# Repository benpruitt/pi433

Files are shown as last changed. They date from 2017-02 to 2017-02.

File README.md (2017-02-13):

# pi433

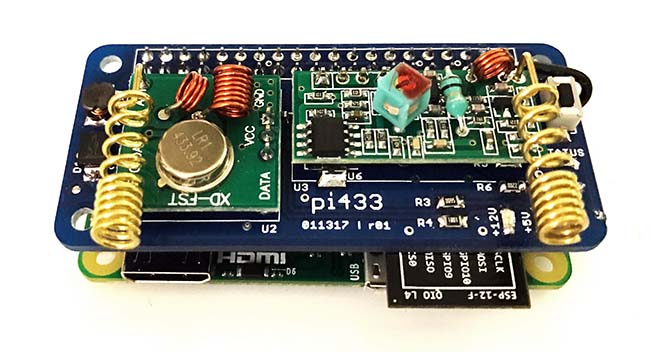
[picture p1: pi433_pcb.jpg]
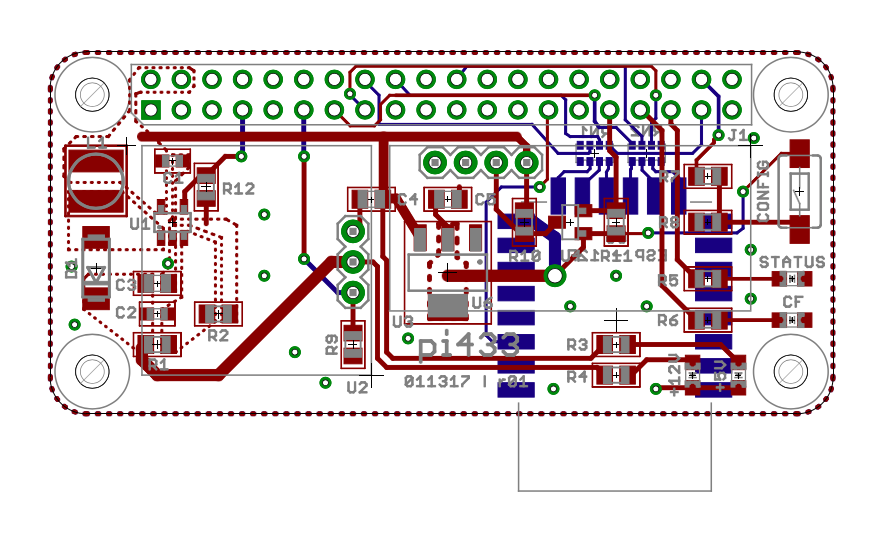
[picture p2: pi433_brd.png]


Raspberry Pi Zero-based Etekcity 433 MHz wireless outlet control. Repo contains
control code and PCB designs.

## Features

* On/off control of Etekcity 433 MHz outlets
* Configurable via a single JSON file
* Ability to group switches into functional groups (e.g., "living room lights")
* Integration with Amazon Echo voice control
* RESTful API exposes outlet control
* Lightweight mobile frontend for manual control

## Dependencies

* [C] wiringPi
* [Python] Cython [optional]
* [Python] gevent
* [Python] rpi.GPIO

## Installation

The latest Rasbian image should include several of the dependencies, including
`RPi-GPIO` and `wiringPi`. The wifi on the Pi zero daughterboard is provided
by an ESP-12F that the Broadcom chip talks to over an SDIO interface. Here
are instructions for updating the device tree & building the module to
support the ESP-12F: https://oshlab.com/esp8266-raspberry-pi-gpio-wifi/

After following the above instructions just set up wifi as usual by editing
`/etc/network/interfaces` and `/etc/wpa_supplicant/wpa_supplicant.conf`.

Next install the remaining python dependencies. I would recommend using
`apt-get` rather than `pip` (to avoid compile times) if you don't mind
installing in your system site packages directory.

Finally:

`sudo python install.py`
_(admin privileges necessary to install systemd service)_

## Installation notes

`pi433` is tested on Raspian under the system Python (2.7.7) / in a
virtual env. `pi433` is not installed into the Python site packages
directory, but rather is copied into `~/.pi433`. The install script copies
the main module directory along with the cli into `~/.pi433` and creates /
configures the `systemd` service necessary to run `pi433` at startup.

The repo contains a pre-built version of the Cython wrapper for the rc-switch
library, so unless you make modifications you shouldn't need Cython. (although
if you do need it, make sure you install via `sudo apt-get install cython`
to avoid the lonnnngg build time you'll experience through `pip`).

## Configuration

The included `config.json` file is also copies into `~/.pi433` and contains
the specifications for the RF outlets / groups that you want to control.

## Todo

* Include RF sniffing interface
* Implement config button functionality
* Better antenna for TX

## Licensing

All code is released under the MIT license with the exception of:

* Unmodified source code from rc-switch is LGPL v2.1:

        pi433/RCSwitch.cpp
        pi433/RCSwitch.h

## Acknowledgements

Inspired by (and derived from [see code comments]):
* rc-switch - https://github.com/sui77/rc-switch
* fauxmo - https://github.com/makermusings/fauxmo / https://github.com/n8henrie/fauxmo

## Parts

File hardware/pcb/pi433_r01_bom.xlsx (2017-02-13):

UID | REF | PART TYPE | #/BOARD | DES | MFG DES | MFG P/N | MFG | SUPPLIER | SUPPLIER P/N | UNIT SIZE | $/UNIT | $/BOARD | DIGIKEY ORDER 1/7/16
PI433_01_01 | R1 | Resistor | 1 | 0805 432k | RES SMD 432K OHM 1% 1/8W 0805 | RC0805FR-07432KL (http://www.digikey.com/product-detail/en/yageo/RC0805FR-07432KL/311-432KCRCT-ND/730906) | Yageo | Digikey | 311-432KCRCT-ND (http://www.digikey.com/product-detail/en/yageo/RC0805FR-07432KL/311-432KCRCT-ND/730906) | 1 | 0.1 | 0.1 | 4
PI433_01_02 | R2 | Resistor | 1 | 0805 49.9k | RES SMD 49.9K OHM 1% 1/8W 0805 | RC0805FR-0749K9L (http://www.digikey.com/product-detail/en/yageo/RC0805FR-0749K9L/311-49.9KCRCT-ND/730932) | Yageo | Digikey | 311-49.9KCRCT-ND (http://www.digikey.com/product-detail/en/yageo/RC0805FR-0749K9L/311-49.9KCRCT-ND/730932) | 1 | 0.1 | 0.1 | 4
PI433_01_03 | R3 | Resistor | 1 | 0805 560 | RES SMD 560 OHM 1% 1/8W 0805 | RC0805FR-07560RL (http://www.digikey.com/product-detail/en/yageo/RC0805FR-07560RL/311-560CRCT-ND/730983) | Yageo | Digikey | 311-560CRCT-ND (http://www.digikey.com/product-detail/en/yageo/RC0805FR-07560RL/311-560CRCT-ND/730983) | 1 | 0.1 | 0.1 | 4
PI433_01_04 | R4 | Resistor | 1 | 0805 1.8k | RES SMD 1.8K OHM 1% 1/8W 0805 | RC0805FR-071K8L (http://www.digikey.com/product-detail/en/yageo/RC0805FR-071K8L/311-1.80KCRCT-ND/730467) | Yageo | Digikey | 311-1.80KCRCT-ND (http://www.digikey.com/product-detail/en/yageo/RC0805FR-071K8L/311-1.80KCRCT-ND/730467) | 1 | 0.1 | 0.1 | 4
PI433_01_05 | R5, R6 | Resistor | 2 | 0805 220 | RES SMD 220 OHM 1% 1/8W 0805 | RC0805FR-07220RL (http://www.digikey.com/product-detail/en/yageo/RC0805FR-07220RL/311-220CRCT-ND/730688) | Yageo | Digikey | 311-220CRCT-ND (http://www.digikey.com/product-detail/en/yageo/RC0805FR-07220RL/311-220CRCT-ND/730688) | 1 | 0.1 | 0.2 | 8
PI433_01_06 | R7 | Resistor | 1 | 0805 1k | RES SMD 1K OHM 1% 1/8W 0805 | RC0805FR-071KL (http://www.digikey.com/product-detail/en/yageo/RC0805FR-071KL/311-1.00KCRCT-ND/730391) | Yageo | Digikey | 311-1.00KCRCT-ND (http://www.digikey.com/product-detail/en/yageo/RC0805FR-071KL/311-1.00KCRCT-ND/730391) | 1 | 0.1 | 0.1 | 4
PI433_01_07 | R8, R9, R10, R11, R12 | Resistor | 5 | 0805 10k | RES SMD 10K OHM 1% 1/8W 0805 | RC0805FR-0710KL (http://www.digikey.com/product-detail/en/yageo/RC0805FR-0710KL/311-10.0KCRCT-ND/730482) | Yageo | Digikey | 311-10.0KCRCT-ND (http://www.digikey.com/product-detail/en/yageo/RC0805FR-0710KL/311-10.0KCRCT-ND/730482) | 1 | 0.1 | 0.5 | 20
PI433_01_08 | C1 | Capacitor | 1 | 0603 0.1 uF | CAP CER 1UF 10V X5R 0603 | GRM188R61A105K | Murata | Digikey | 490-6408-1-ND (http://www.digikey.com/product-detail/en/murata-electronics-north-america/GRM188R61A105KA61J/490-6408-1-ND/3845605) | 1 | 0.1 | 0.1 | 4
PI433_01_09 | C2 | Capacitor | 1 | 0603 15 pF | CAP CER 15PF 50V NP0 0603 | GCM1885C1H150JA16D (http://www.digikey.com/product-detail/en/murata-electronics-north-america/GCM1885C1H150JA16D/490-4957-1-ND/1765276) | Murata | Digikey | 490-4957-1-ND (http://www.digikey.com/product-detail/en/murata-electronics-north-america/GCM1885C1H150JA16D/490-4957-1-ND/1765276) | 1 | 0.1 | 0.1 | 4
PI433_01_10 | C3 | Capacitor | 1 | 0603 4.7 uF | CAP CER 4.7UF 16V X5R 0805 | GRM21BR61C475K | Murata | Digikey | 490-7214-1-ND (http://www.digikey.com/product-detail/en/murata-electronics-north-america/GRM21BR61C475KA88K/490-7214-1-ND/3991200) | 1 | 0.17 | 0.17 | 4
PI433_01_11 | L1 | Inductor | 1 | 4.7 uH 1.7 A | FIXED IND 4.7UH 1.7A 94 MOHM SMD | SDR0403-4R7ML | Bourns | Digikey | SDR0403-4R7MLCT-ND (http://www.digikey.com/product-detail/en/bourns-inc/SDR0403-4R7ML/SDR0403-4R7MLCT-ND/2127096) | 1 | 0.47 | 0.47 | 4
PI433_01_12 | U1 | Regulator | 1 | 1.4A boost | IC REG BOOST ADJ 1.4A TSOT23-5 | SC4503TSKTRT (http://www.digikey.com/product-detail/en/semtech-corporation/SC4503TSKTRT/SC4503TSKCT-ND/1249536) | Semtech | Digikey | SC4503TSKCT-ND (http://www.digikey.com/product-detail/en/semtech-corporation/SC4503TSKTRT/SC4503TSKCT-ND/1249536) | 1 | 1.92 | 1.92 | 4
PI433_01_13 | U2, U3 | 433 MHz Transmitter / Receiver | 1 | 433 MHz Transmitter / Receiver | N/A | N/A | SMAKN | Amazon | B00M2CUALS (https://www.amazon.com/SMAKN-433Mhz-Transmitter-Receiver-Arduino/dp/B00M2CUALS) | 1 | 6.66 | 6.66
PI433_01_14 | U4 | MOSFET | 1 | Level coversion MOSFET | MOSFET N-CH 50V 220MA SOT-23 | BSS138 (http://www.digikey.com/product-detail/en/fairchild-on-semiconductor/BSS138/BSS138CT-ND/244294) | Fairchild | Digikey | BSS138CT-ND (http://www.digikey.com/product-detail/en/fairchild-on-semiconductor/BSS138/BSS138CT-ND/244294) | 1 | 0.22 | 0.22 | 4
PI433_01_15 | U5 | WIFI Transceiver | 1 | SDIO interface WiFi transceiver | N/A | ESP-12F | Yison | GearBest | ESP-12F (http://www.gearbest.com/transmitters-receivers-module/pp_315638.html) | 1 | 3.19 | 3.19 | 4
PI433_01_16 | S1 | Switch | 1 | Tactile switch | SWITCH TACTILE SPST-NO 0.05A 12V | RS-032G05A3-SM RT (http://www.digikey.com/product-detail/en/c-k/RS-032G05A3-SM-RT/CKN10388CT-ND/2747197) | C&K | Digikey | CKN10388CT-ND (http://www.digikey.com/product-detail/en/c-k/RS-032G05A3-SM-RT/CKN10388CT-ND/2747197) | 1 | 0.56 | 0.56 | 4
PI433_01_17 | LED1, LED2, LED3, LED4 | LED | 4 | LED | LED GREEN CLEAR 0805 SMD | LTST-C171GKT (http://www.digikey.com/product-detail/en/lite-on-inc/LTST-C171GKT/160-1423-1-ND/386792) | Lite-On | Digikey | 160-1423-1-ND (http://www.digikey.com/product-detail/en/lite-on-inc/LTST-C171GKT/160-1423-1-ND/386792) | 1 | 0.29 | 1.16 | 16

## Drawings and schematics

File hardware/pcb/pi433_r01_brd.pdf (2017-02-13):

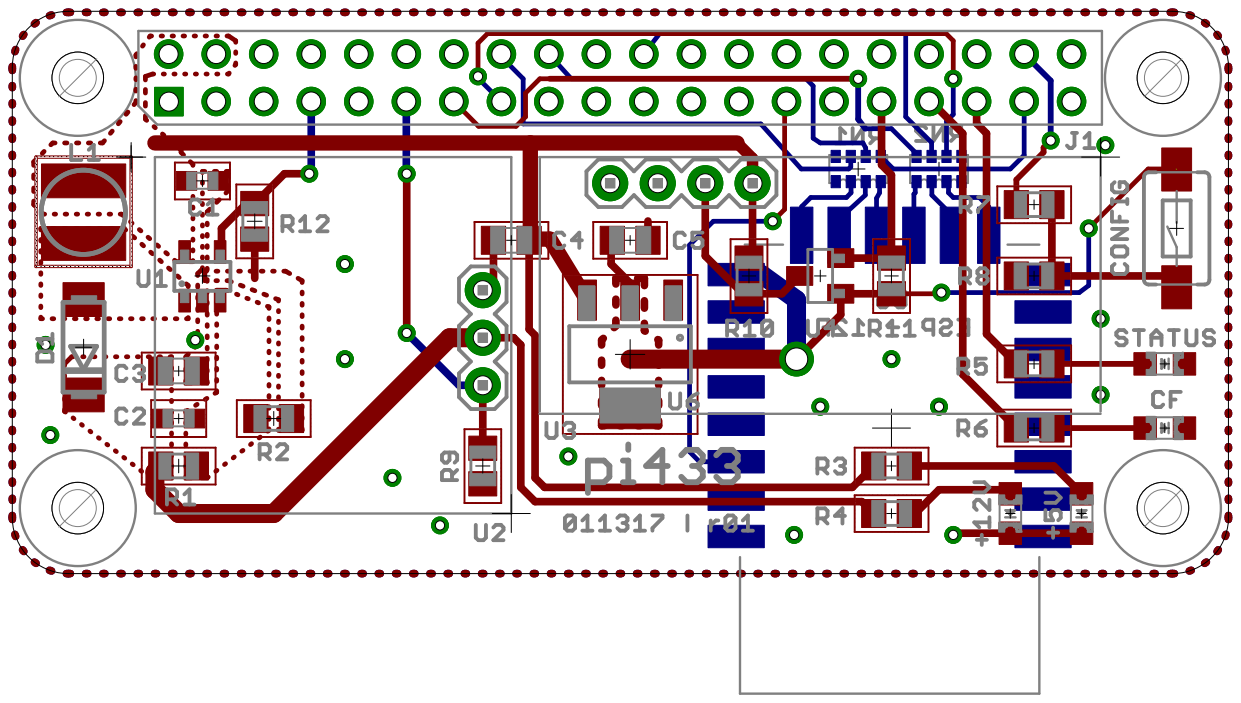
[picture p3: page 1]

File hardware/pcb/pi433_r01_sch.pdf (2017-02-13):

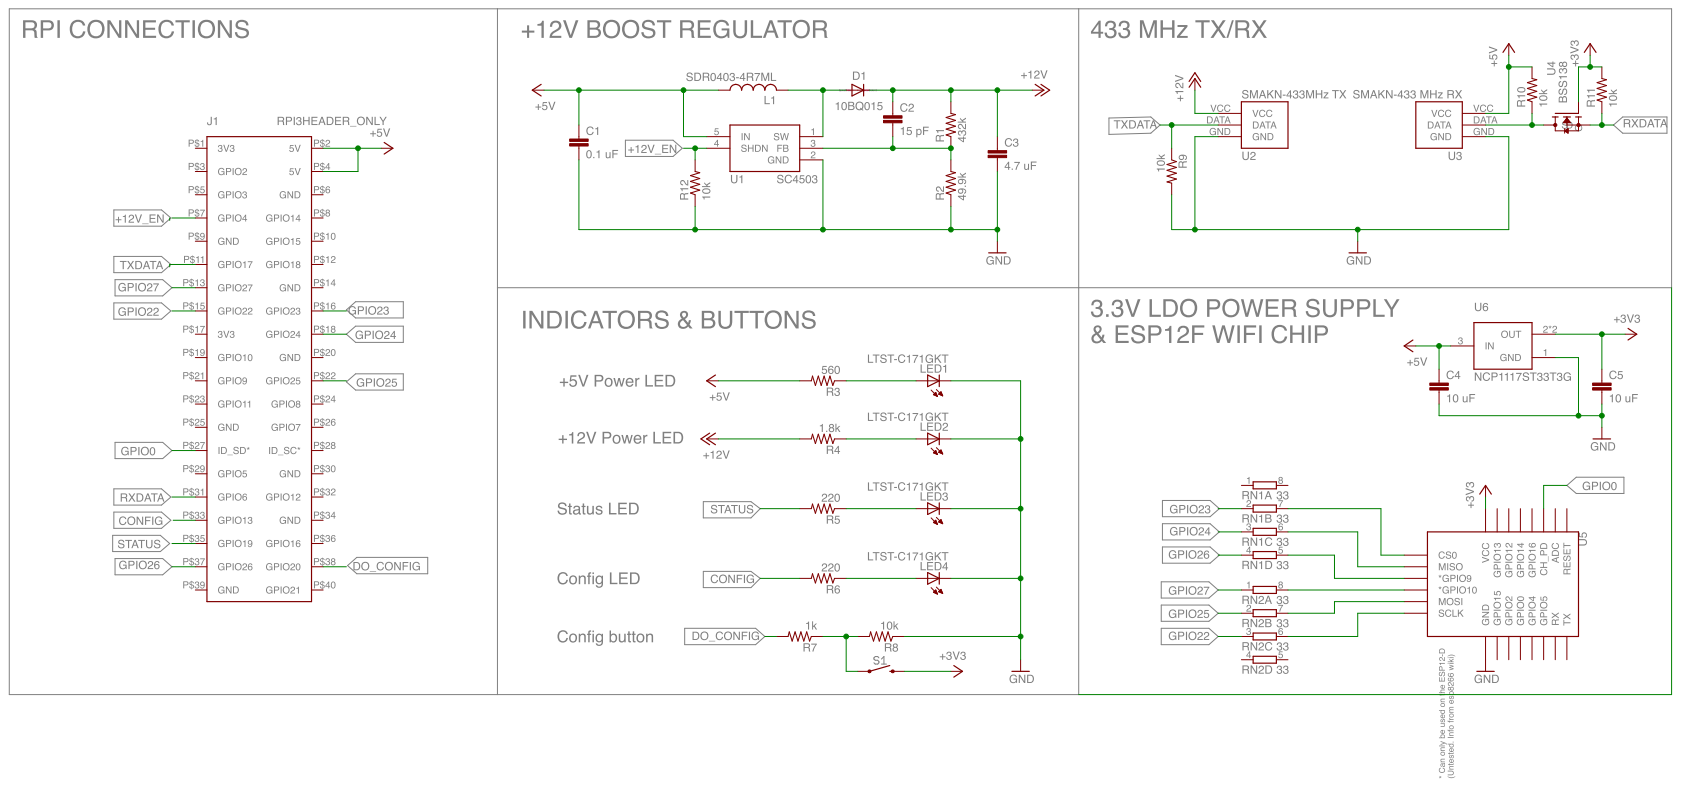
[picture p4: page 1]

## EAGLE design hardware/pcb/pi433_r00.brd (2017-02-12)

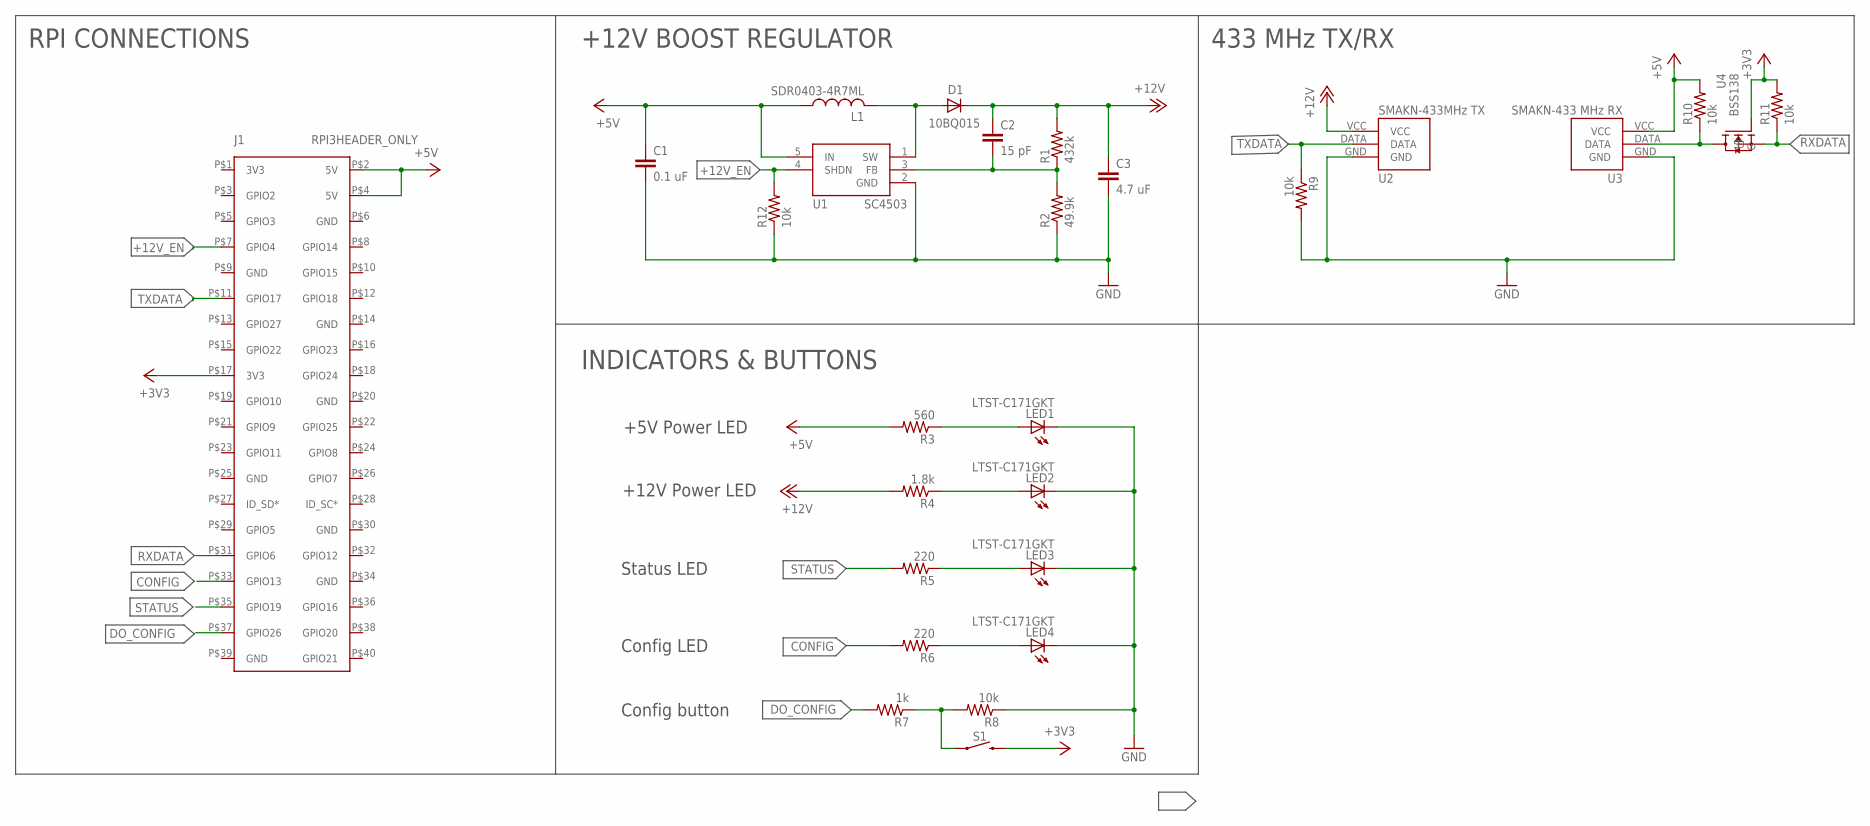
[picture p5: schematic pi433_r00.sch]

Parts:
C1: 0.1 uF; C0603
C2: 15 pF; C0603
C3: 4.7 uF; C0805
D1: 10BQ015; DO214AA
J1: RPI3HEADER_ONLY; RPI3-HEADER_ONLY
L1: SDR0403-4R7ML; SDR0403
LED1, LED2, LED3, LED4: LTST-C171GKT; CHIPLED_0805
R1: 432k; R0805
R2: 49.9k; R0805
R3: 560; R0805
R4: 1.8k; R0805
R5, R6: 220; R0805
R7: 1k; R0805
R8, R9, R10, R11, R12: 10k; R0805
S1: MOMENTARY-SWITCH-SPST-SMD-6.0X3.5MM; TACTILE_SWITCH_SMD_6.0X3.5MM
U1: SC4503; TSOT-23-5
U2: SMAKN-433TX
U3: SMAKN-433RX
U4: BSS138

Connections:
+3V3: J1.P$17 (3V3), R11.2, S1.2, U4.G
+5V: C1.1, J1.P$2 (5V), J1.P$4 (5V), L1.P$1 (1), R3.2, R10.2, U1.5 (IN), U3.VCC
+12V: C2.1, C3.1, D1.C, R1.2, R4.2, U2.VCC
+12V_EN: J1.P$7 (GPIO4), R12.2, U1.4 (SHDN)
CONFIG: J1.P$33 (GPIO13), R6.2
DO_CONFIG: J1.P$37 (GPIO26), R7.2
GND: C1.2, C3.2, LED1.C, LED2.C, LED3.C, LED4.C, R2.1, R8.1, R9.2, R12.1, U1.2 (GND), U2.GND, U3.GND
unnamed: LED1.A, R3.1
unnamed: D1.A, L1.P$2 (2), U1.1 (SW)
unnamed: LED2.A, R4.1
unnamed: LED3.A, R5.1
unnamed: C2.2, R1.1, R2.2, U1.3 (FB)
unnamed: LED4.A, R6.1
unnamed: R7.1, R8.2, S1.1
unnamed: R10.1, U3.DATA, U4.D
RXDATA: J1.P$31 (GPIO6), R11.1, U4.S
STATUS: J1.P$35 (GPIO19), R5.2
TXDATA: J1.P$11 (GPIO17), R9.1, U2.DATA

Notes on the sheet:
RPI CONNECTIONS
+12V BOOST REGULATOR
+5V Power LED
+12V Power LED
Status LED
INDICATORS & BUTTONS
Config LED
Config button
433 MHz TX/RX

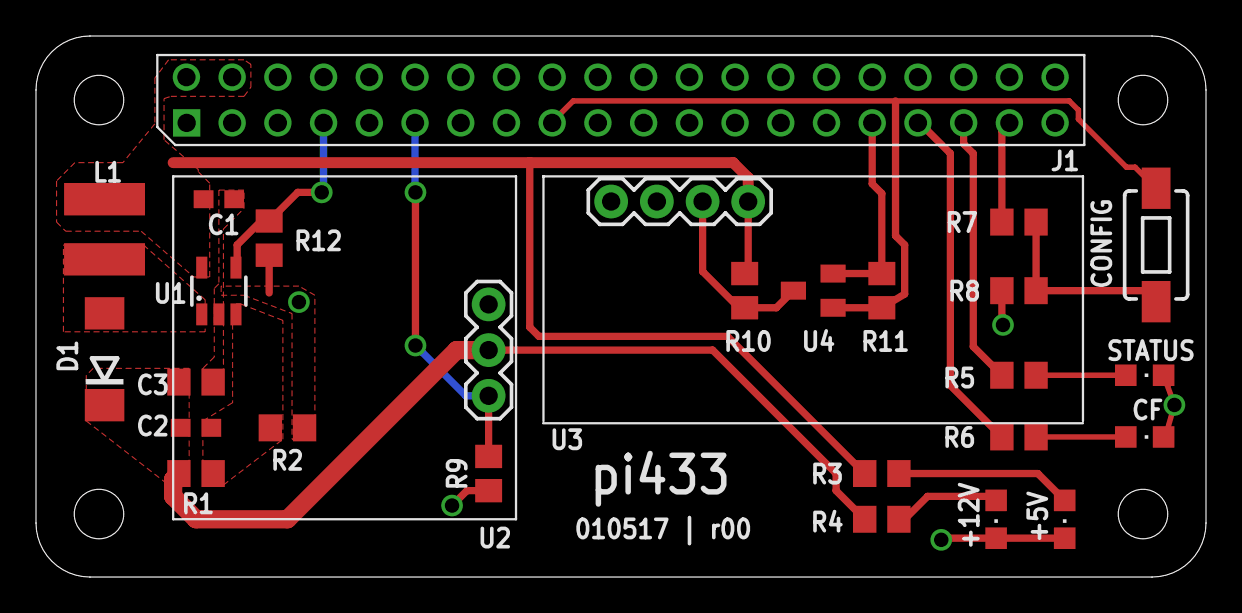
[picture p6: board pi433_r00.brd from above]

Board: 2 copper layers, 65.0 x 30.1 mm, 27 parts (0 on the bottom side), 18 nets.

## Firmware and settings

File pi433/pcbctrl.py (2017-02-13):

'''
pi433.pcbctrl
(c) Ben Pruitt, 2017 [MIT License, see LICENSE]

Methods to control the pi433 PCB features (12V boost converter, status LEDs)

'''
import atexit

from gevent import sleep
from gevent.lock import Semaphore
import RPi.GPIO as GPIO

GPIO_INIT = False
BOOST_12V_PIN = 4
STATUS_LED_PIN = 19

STATUS_LED_SEMA = Semaphore()


def _initGPIO():
    global GPIO_INIT
    if not GPIO_INIT:
        GPIO.setmode(GPIO.BCM)
        GPIO.setup(BOOST_12V_PIN, GPIO.OUT)
        GPIO.setup(STATUS_LED_PIN, GPIO.OUT)
        atexit.register(GPIO.cleanup)
        GPIO_INIT = True


def turnStatusLEDOn():
    ''' Turn the green status LED on
    '''
    _initGPIO()
    GPIO.output(STATUS_LED_PIN, 1)


def turnStatusLEDOff():
    ''' Turn the green status LED off
    '''
    _initGPIO()
    GPIO.output(STATUS_LED_PIN, 0)


def blinkStatusLED(blink_str='0101', blink_rate=0.05):
    ''' Blink the green status LED

    Args:
        blink_str (str): binary string representing LED states (0-off, 1-on)
        blink_rate (str): delay between `blink_str` states
    '''
    _initGPIO()
    # Ensure that only one greenlet is blinking the LED at a given time
    # Status LED operation is not mission critical
    if STATUS_LED_SEMA.acquire(blocking=False):
        for s in blink_str:
            GPIO.output(STATUS_LED_PIN, int(s))
            sleep(blink_rate)
        STATUS_LED_SEMA.release()


def turn12VOn():
    ''' Turn the 12V boost converter on
    '''
    _initGPIO()
    GPIO.output(BOOST_12V_PIN, 1)


def turn12VOff():
    ''' Turn the 12V boost converter on
    '''
    _initGPIO()
    GPIO.output(BOOST_12V_PIN, 0)

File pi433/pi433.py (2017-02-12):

'''
pi433.pi433
(c) Ben Pruitt, 2017 [MIT License, see LICENSE]

Main entry point for pi433

'''
import logging
import json
import os
import sys
import time

from gevent import spawn, joinall, sleep

from .switch import EtekcitySwitch, SwitchGroup
from .ssdp import SSDPServer
from .pcbctrl import turn12VOn, turnStatusLEDOn
from .webserver import initServer
from .util import byteify, getLocalIP

FORMAT = "[pi433] %(asctime)-15s :: %(message)s"
logging.basicConfig(format=FORMAT, level=logging.DEBUG)

NETWORK_INIT_TIMEOUT_M = 5
DEFAULT_CONFIG_FP = os.path.expanduser('~/.pi433/config.json')


def startPi433(config_fp=DEFAULT_CONFIG_FP):
    switches = []
    groups = []

    # Wait for the network to come up
    t1 = time.time()
    while True:
        if time.time() - t1 > (NETWORK_INIT_TIMEOUT_M * 60):
            logging.warning('Timeout waiting for device network to come up')
            sys.exit(1)
        try:
            getLocalIP()
            break
        except:
            sleep(5)

    # Load config file from fp
    with open(config_fp) as fh:
        config_dict = byteify(json.load(fh))

    # Init switch objects
    for switch_cf in config_dict.get('switches', []):
        switches.append(
            EtekcitySwitch(
                switch_cf['name'],
                switch_cf['port'],
                switch_cf['on_code'],
                switch_cf['off_code']
            )
        )

    # Init group objects
    for group_cf in config_dict.get('groups', []):
        groups.append(
            SwitchGroup(
                group_cf['name'],
                group_cf['port'],
                group_cf['switches']
            )
        )
    # Init SSDP server
    ssdpserver = SSDPServer(switches + groups)
    # Init webserver
    webserver = initServer()
    # Spin up greenlets
    glts = [spawn(s.run) for s in (switches + groups)] + [spawn(ssdpserver.run)]
    # Turn on 12V boost converter and status LED
    turn12VOn()
    turnStatusLEDOn()
    logging.info('SSDP server and switch servers started')
    webserver.serve_forever()
    joinall(glts)

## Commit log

2017-02-13 add pdf version of r01 pcb design, update readme
2017-02-13 add esp12-f to r01 bom
    [pi433_r01_bom.xlsx]

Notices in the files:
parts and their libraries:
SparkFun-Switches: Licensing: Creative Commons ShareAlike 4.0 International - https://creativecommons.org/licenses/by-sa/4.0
